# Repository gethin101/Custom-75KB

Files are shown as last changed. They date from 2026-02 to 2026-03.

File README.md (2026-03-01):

# Gethin-75 
A custom 75% mechanical keyboard with macro keys powered by a Raspberry pi pico and KMK firmware that I designed and built during Hackclub's Blueprint program - [project link](https://blueprint.hackclub.com/projects/12386)

I made this project to learn the fundamentals of how keyboards and macropads work, to improve my PCB design skills by learning how switch matrixes work and to get more familiar with modelling parts in CAD for 3D printing.

   

  <a href="#Keys">BOM</a> •
  <a href="#Images">Images</a> •
  <a href="#Firmware">Firmware</a> •
  <a href="#BOM">BOM</a> •
  <a href="#Full Wiring Table">Wiring</a> •
  <a href="#Keys">Keys</a> •
  <a href="#Stabilizers">Stabilizers</a> 

# Key Features
- **93 programmable macro keys**
- **Custom 2-layer PCB**
- **Powered by a Raspberry Pi Pico**
- **Custom KMK firmware**
- **Simple USB connectivity**
- **Inter-changable Cherry MX key switches**
- **3D printed case & plate**
- **Rubber feet pads for stability**
- **Easy assembly with no screws**

# Images
Here, you can see my KiCad schematic, PCB layout and 3D model of my PCB. On the right, you can see my keyboard bottom case I modelled in Fusion 360 as well as my custom plate and an assembly image.
<br>

<details>
<summary>Click to see schematic</summary>
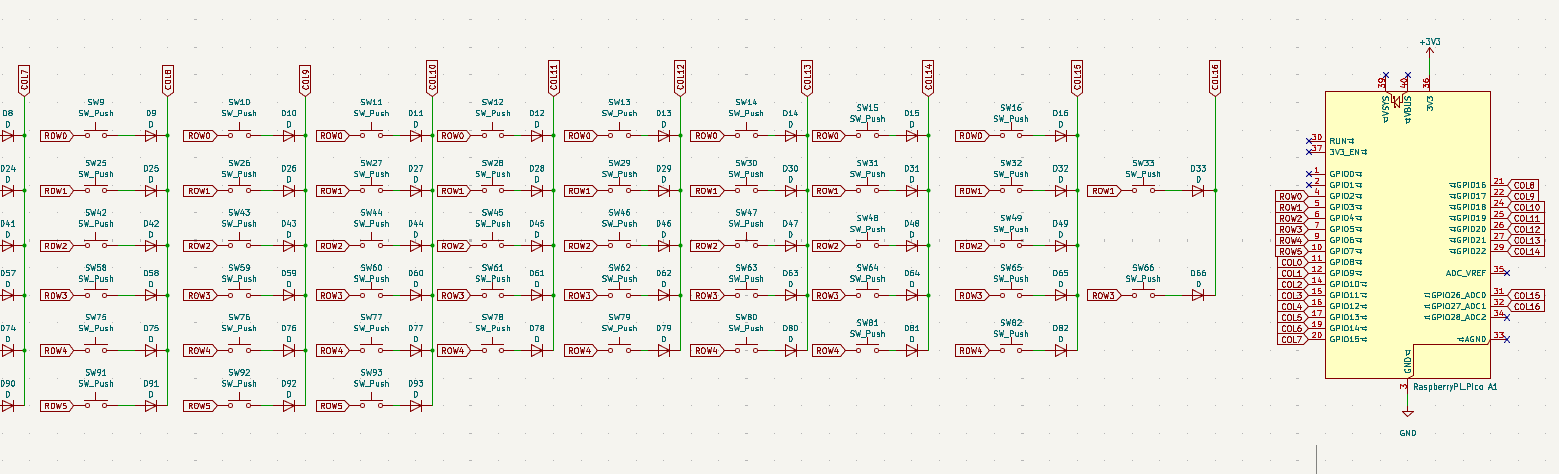
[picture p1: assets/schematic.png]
schematic

</details>

<details>
<summary>Click to see PCB</summary>
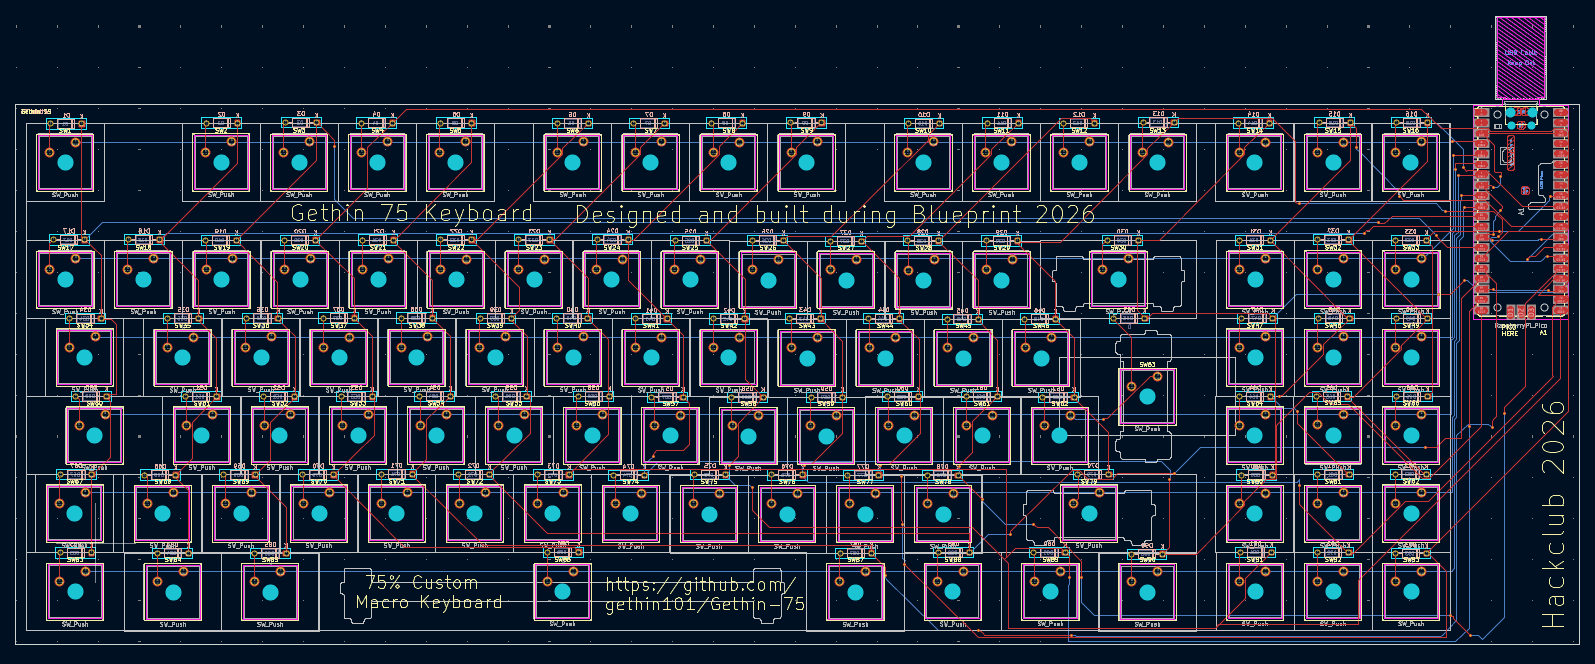
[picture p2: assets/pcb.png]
PCB

</details>

<details>
<summary>Click to see 3D PCB</summary>
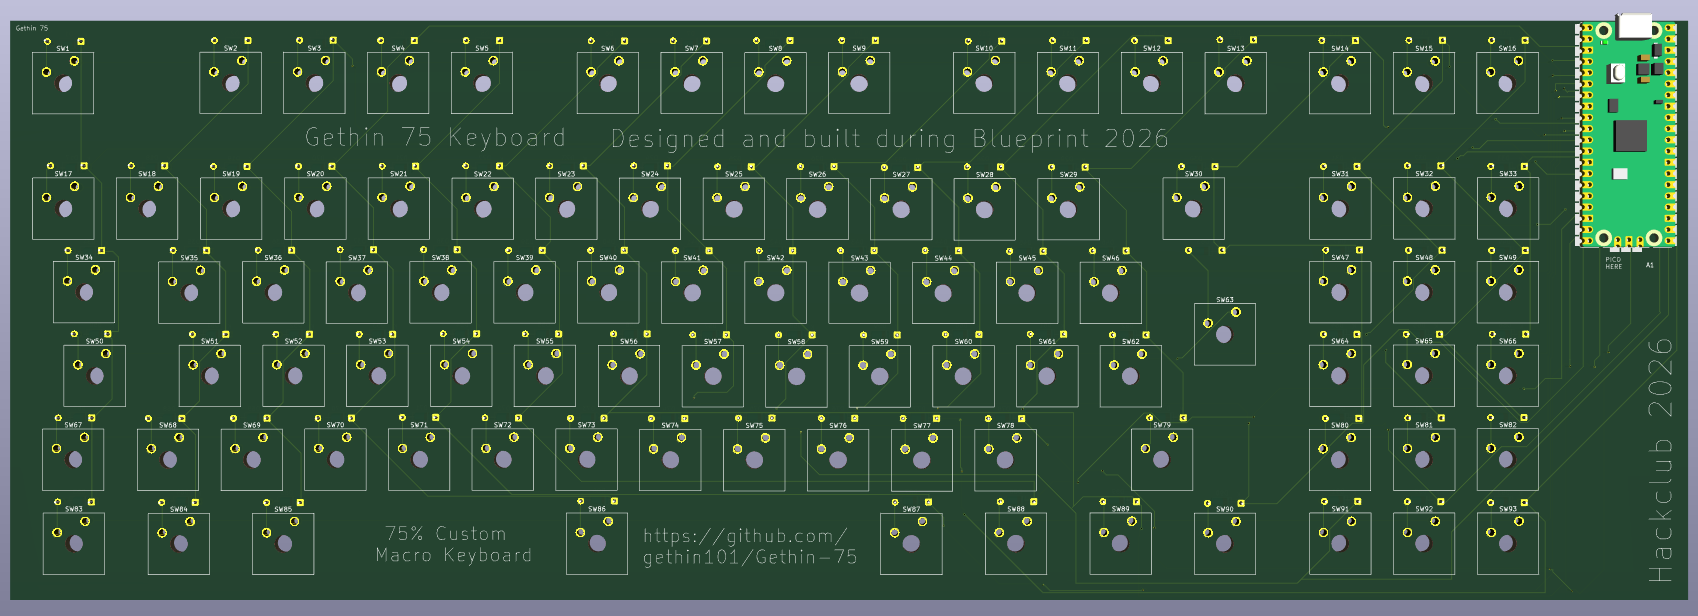
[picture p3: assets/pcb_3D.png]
3d pcb

</details>

**Click any of the images below or click above to see it in more detail**

| PCB | CAD |
|-----|-----|
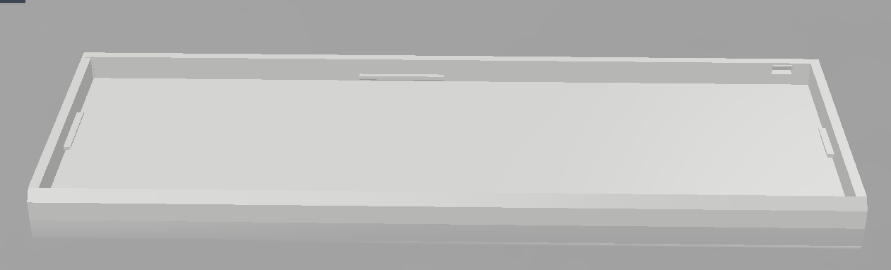
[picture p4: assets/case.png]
|  |  |
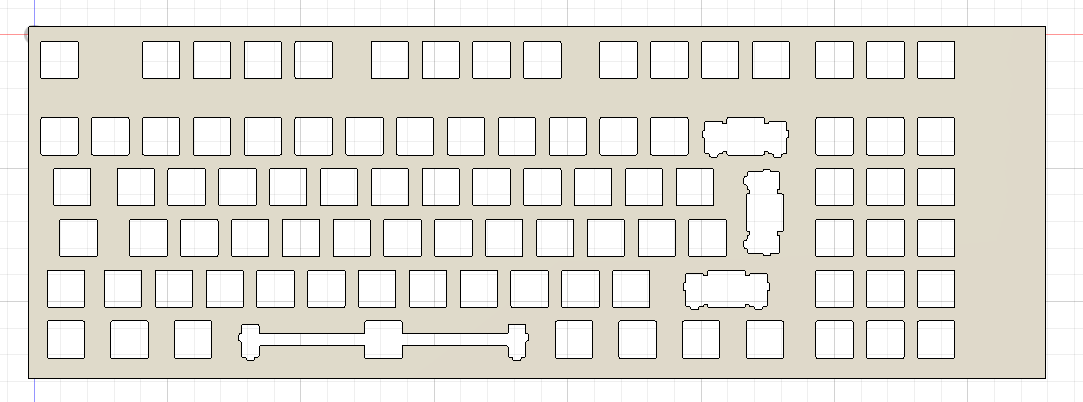
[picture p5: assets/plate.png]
|  |  |
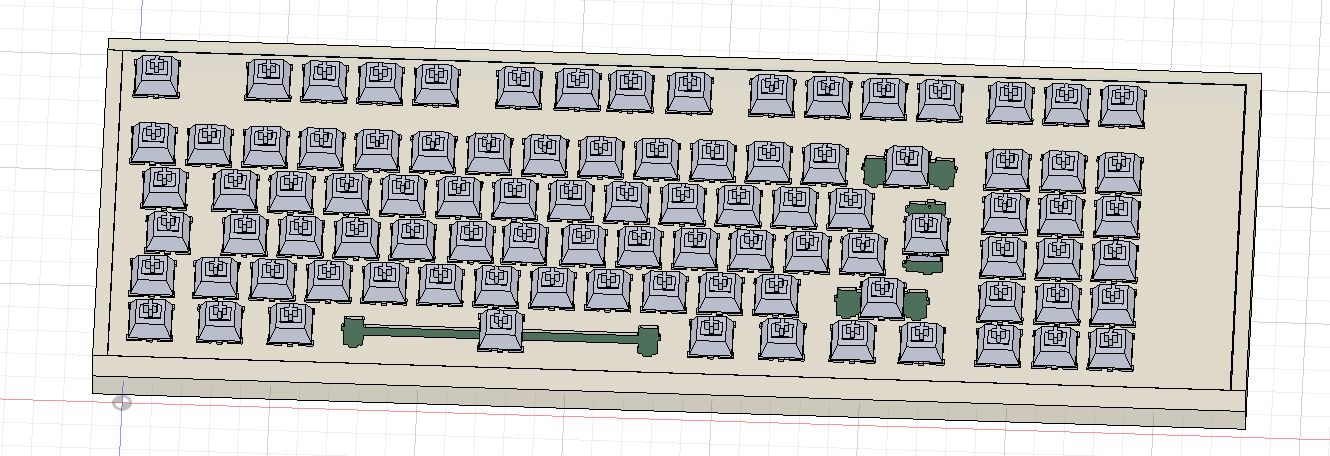
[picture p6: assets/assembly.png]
|  |  |

<details>
<summary>Click to see case model</summary>
case
</details>

<details>
<summary>Click to see plate model</summary>
plate
</details>

<details>
<summary>Click to see keyboard assembly</summary>
assembly
</details>

 

 # Full Wiring Table

<details>
<summary>Click to see full wiring table</summary>
<br>

| Net | GPIO | Notes |
|---|---|---|
| ROW0  | GP2  | Matrix  |
| ROW1  | GP3  | Matrix  |
| ROW2  | GP4  | Matrix  |
| ROW3  | GP5  | Matrix  |
| ROW4  | GP6  | Matrix  |
| ROW5  | GP7  | Matrix  |
| COL0  | GP8  | Matrix  |
| COL1  | GP9  | Matrix  |
| COL2  | GP10 | Matrix  |
| COL3  | GP11 | Matrix  |
| COL4  | GP12 | Matrix  |
| COL5  | GP13 | Matrix  |
| COL6  | GP14 | Matrix  |
| COL7  | GP15 | Matrix  |
| COL8  | GP16 | Matrix  |
| COL9  | GP17 | Matrix  |
| COL10 | GP18 | Matrix  |
| COL11 | GP19 | Matrix  |
| COL12 | GP20 | Matrix  |
| COL13 | GP21 | Matrix  |
| COL14 | GP22 | Matrix  |
| COL15 | GP26 | Matrix  |
| COL16 | GP27 | Matrix  |
| 3V3 | +3v3 | Pico |
| GND | GND  | Common  |

</details>

# Firmware
I have written my custom keyboard code in CircuitPython using KMK to control the keystrokes and I have made a macro handler at the start that means I can change the function of any of my keys whenever I want.

My macro keys at the moment:
- Previous song
- Play / Pause
- Next song
- Volume down
- Volume up
- Lock
- File Explorer
- Task Manager

**Setup:**
- Flash [CircuitPython](/Firmware/adafruit-circuitpython-raspberry_pi_pico2-en_GB-10.1.3.uf2) onto my pico
- Download KMK from [Github](/Firmware/kmk) and copy to root
- Download [code.py](/Firmware/code.py) onto the pico

# Keys
My keyboard is a 75% keyboard with a total of 93 keys - 85 normal and 8 custom macro keys.

Here is the link to my [keyboard layout](https://www.keyboard-layout-editor.com/#/gists/a3df558aee879b924d336356534e8c5d) <br>

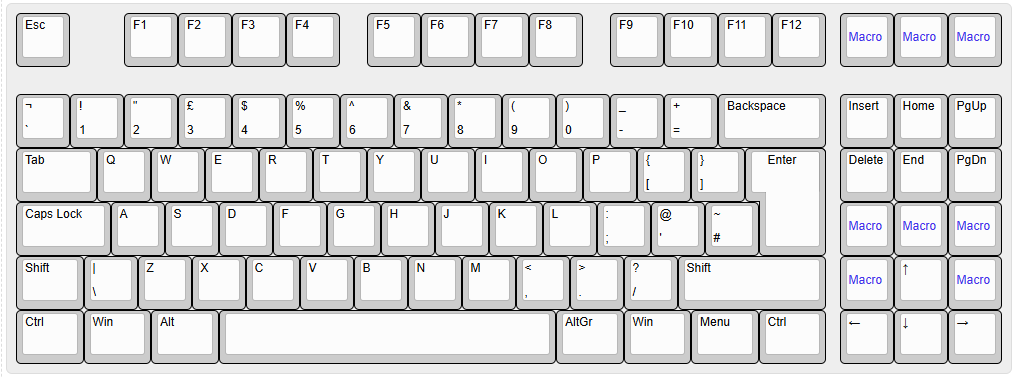
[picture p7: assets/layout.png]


---

# BOM
| Qty | Item | Notes | Cost (£) | USD ($) | Link |
|---|-----|---|---|---|---|
| 100 | MX-Style key switches | Black 100pcs | £15.28 | $20.60 | [AE](https://www.aliexpress.com/item/1005006091988869.html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)
| 126 | Cherry MX Key caps | Yunhu White | £2.04 | $2.75 | [AE](https://www.aliexpress.com/item/1005007321700850.html) |
| 1 | Raspberry Pi Pico | 2H | £5.40 | $7.28 | [PiHut](https://thepihut.com/products/raspberry-pi-pico-2?variant=54063366701441) |
| 5 | Plate-mount stabilizers | 4x 2u and 6.25u | £4.29 | $5.79 | [AE](https://www.aliexpress.com/item/1005001831944910.html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) |
| 100 | 1N4148 diodes | Through-hole | £0.76 | $1.02 | [AE](https://www.aliexpress.com/item/4001126137167.html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) |
| 50 | Rubber feet pads | 13x5.5mm | £0.76 | $1.02 | [AE](https://www.aliexpress.com/item/1005006832476105.html) |
| 5 | Custom PCB | (Quote estimate) | £ | $ | [JLCPCB]([https://www.aliexpress.com/item/1005006832476105.html](https://jlcpcb.com/)) |
| 1 | Micro USB -> USB cable | 0.5m | £0.76 | $1.01 | [AE](https://www.aliexpress.com/item/1005010780201113.html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) |
| 2 | 3D Print case and plate | #printing-legion | £ | $ | [Slack](https://hackclub.enterprise.slack.com/archives/C083P4FJM46) |
| **390** | **Total cost:** | **Not counting shipping** | **£29.29** | **$40.48** | [BOM](/Bom.md) |

# Stabilizers 

My spacebar, left shift, right shift, enter and backspace all need MX stabilizers as they are above 2u and these will be plate-mounted.

| Key | Size | Stabilizer |
|-----|---|---|
|Space| 6.25u| 6.25u plate-mount |
|R-Shift| 2.75u | 2u plate-mount |
|Enter | 2.25u | 2u plate-mount |
|Backspace | 2u | 2u plate-mount |

---

# Blueprint requirements

- [✅] A short description of what your project is  
- [✅] A couple of sentences on how to use your project  
- [✅] A couple of sentences on why you made the project  

- [✅ ] Screenshot of a full 3D model of your project  
- [✅ ] Screenshot of your PCB (if applicable)  
- [✅ ] Wiring diagram (if any wiring is not on a PCB)  
- [✅] Bill of Materials (BOM) in table format at the end of the README, with links  

- [✅] Fully original, customized design (not a direct copy of any guide)  
- [✅] Complete CAD assembly including all components (electronics included)  
- [✅] Firmware present (even if untested)  
- [ ] Design sanity‑checked with someone else  

- [ ] BOM in CSV format in the root directory, with links  
- [ ] PCB source files (.kicad_pro, .kicad_sch, gerbers.zip, etc.) if applicable  
- [ ] A .STEP file of the full 3D CAD model including electronics  
- [ ] Source CAD files (.f3d, .FCStd, etc., or OnShape public link in README)  
- [ ] All other project files included (firmware, libraries, references, etc.)  
- [ ] Repository organized into readable, logical folders  

> ⚠️ **Important:** Missing a complete .STEP file with all electronics and CAD will result in project rejection.

Designed and built by [@gethin101](https://github.com/gethin101)

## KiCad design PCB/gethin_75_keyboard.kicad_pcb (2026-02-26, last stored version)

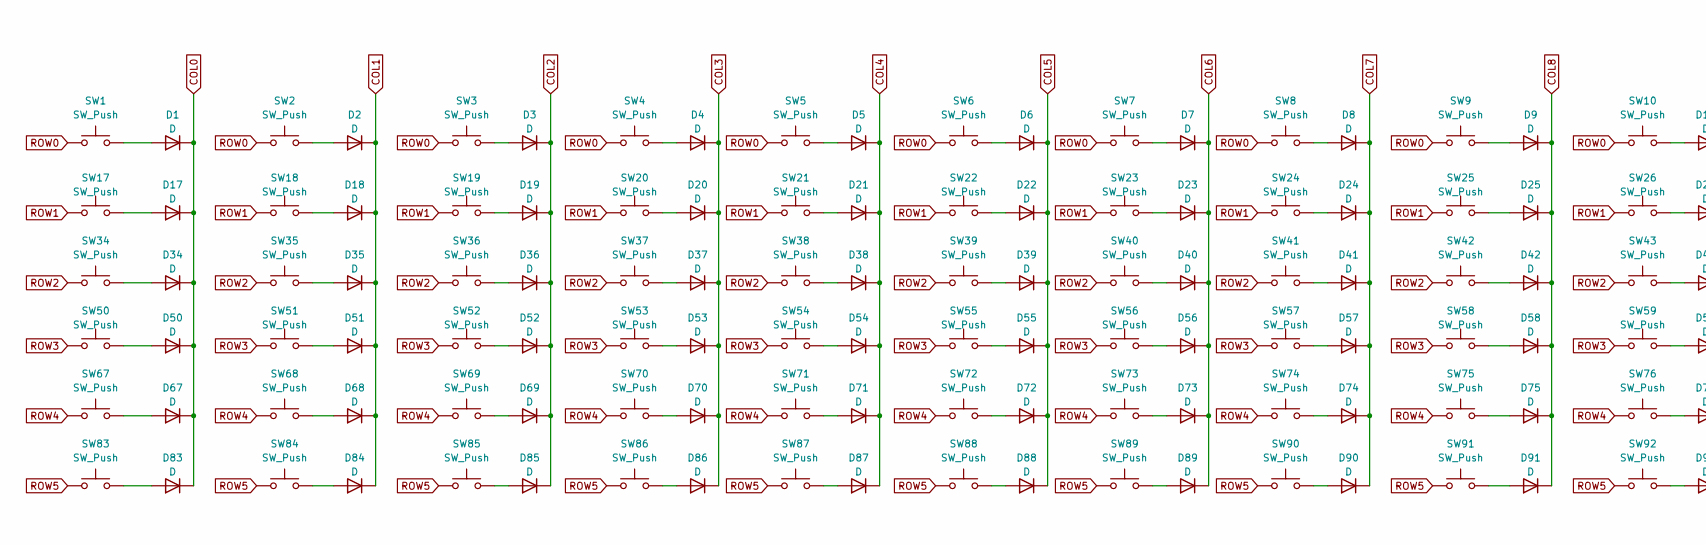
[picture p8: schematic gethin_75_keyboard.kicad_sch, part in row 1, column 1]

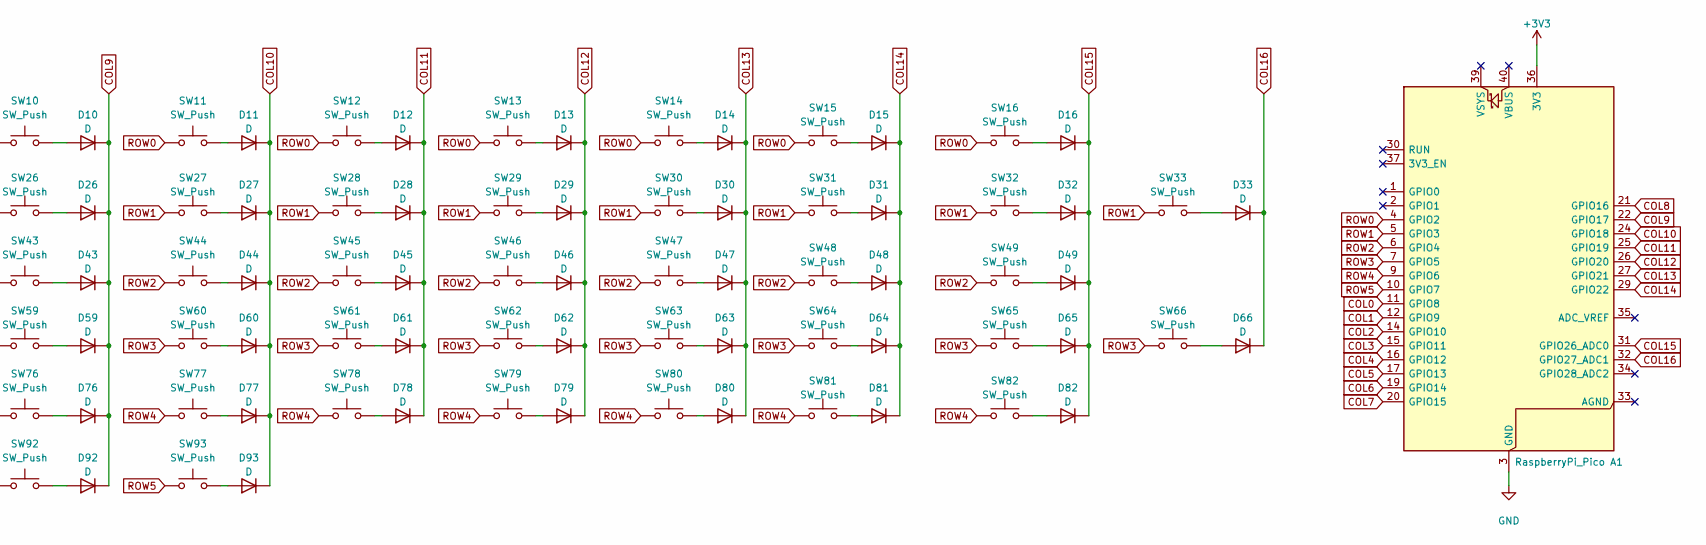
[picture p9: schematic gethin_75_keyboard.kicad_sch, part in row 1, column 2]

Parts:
A1: RaspberryPi_Pico; RaspberryPi_Pico_SMD_HandSolder
D1, D2, D3, D4, D5, D6, D7, D8, D9, D10, D11, D12, D13, D14, D15, D16, D17, D18, D19, D20, D21, D22, D23, D24, D25, D26, D27, D28, D29, D30, D31, D32, D33, D34, D35, D36, D37, D38, D39, D40, D41, D42, D43, D44, D45, D46, D47, D48, D49, D50, D51, D52, D53, D54, D55, D56, D57, D58, D59, D60, D61, D62, D63, D64, D65, D66, D67, D68, D69, D70, D71, D72, D73, D74, D75, D76, D77, D78, D79, D80, D81, D82, D83, D84, D85, D86, D87, D88, D89, D90, D91, D92, D93: D; D_DO-35_SOD27_P7.62mm_Horizontal
SW1, SW2, SW3, SW4, SW5, SW6, SW7, SW8, SW9, SW10, SW11, SW12, SW13, SW14, SW15, SW16, SW17, SW18, SW19, SW20, SW21, SW22, SW23, SW24, SW25, SW26, SW27, SW28, SW29, SW31, SW32, SW33, SW34, SW35, SW36, SW37, SW38, SW39, SW40, SW41, SW42, SW43, SW44, SW45, SW46, SW47, SW48, SW49, SW51, SW52, SW53, SW54, SW55, SW56, SW57, SW58, SW59, SW60, SW61, SW62, SW64, SW65, SW66, SW67, SW68, SW69, SW70, SW71, SW72, SW73, SW74, SW75, SW76, SW77, SW78, SW80, SW81, SW82, SW91, SW92, SW93: SW_Push; SW_Cherry_MX_1.00u_Plate
SW30: SW_Push; SW_Cherry_MX_2.00u_Plate
SW50: SW_Push; SW_Cherry_MX_1.75u_Plate
SW63: SW_Push; SW_Cherry_MX_2.25u_Plate
SW79: SW_Push; SW_Cherry_MX_2.75u_Plate
SW83, SW84, SW85, SW87, SW88, SW89, SW90: SW_Push; SW_Cherry_MX_1.25u_Plate
SW86: SW_Push; SW_Cherry_MX_6.25u_Plate

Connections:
+3V3: A1.36 (3V3)
COL0: A1.11 (GPIO8), D1.1 (K), D17.1 (K), D34.1 (K), D50.1 (K), D67.1 (K), D83.1 (K)
COL1: A1.12 (GPIO9), D2.1 (K), D18.1 (K), D35.1 (K), D51.1 (K), D68.1 (K), D84.1 (K)
COL2: A1.14 (GPIO10), D3.1 (K), D19.1 (K), D36.1 (K), D52.1 (K), D69.1 (K), D85.1 (K)
COL3: A1.15 (GPIO11), D4.1 (K), D20.1 (K), D37.1 (K), D53.1 (K), D70.1 (K), D86.1 (K)
COL4: A1.16 (GPIO12), D5.1 (K), D21.1 (K), D38.1 (K), D54.1 (K), D71.1 (K), D87.1 (K)
COL5: A1.17 (GPIO13), D6.1 (K), D22.1 (K), D39.1 (K), D55.1 (K), D72.1 (K), D88.1 (K)
COL6: A1.19 (GPIO14), D7.1 (K), D23.1 (K), D40.1 (K), D56.1 (K), D73.1 (K), D89.1 (K)
COL7: A1.20 (GPIO15), D8.1 (K), D24.1 (K), D41.1 (K), D57.1 (K), D74.1 (K), D90.1 (K)
COL8: A1.21 (GPIO16), D9.1 (K), D25.1 (K), D42.1 (K), D58.1 (K), D75.1 (K), D91.1 (K)
COL9: A1.22 (GPIO17), D10.1 (K), D26.1 (K), D43.1 (K), D59.1 (K), D76.1 (K), D92.1 (K)
COL10: A1.24 (GPIO18), D11.1 (K), D27.1 (K), D44.1 (K), D60.1 (K), D77.1 (K), D93.1 (K)
COL11: A1.25 (GPIO19), D12.1 (K), D28.1 (K), D45.1 (K), D61.1 (K), D78.1 (K)
COL12: A1.26 (GPIO20), D13.1 (K), D29.1 (K), D46.1 (K), D62.1 (K), D79.1 (K)
COL13: A1.27 (GPIO21), D14.1 (K), D30.1 (K), D47.1 (K), D63.1 (K), D80.1 (K)
COL14: A1.29 (GPIO22), D15.1 (K), D31.1 (K), D48.1 (K), D64.1 (K), D81.1 (K)
COL15: A1.31 (GPIO26_ADC0), D16.1 (K), D32.1 (K), D49.1 (K), D65.1 (K), D82.1 (K)
COL16: A1.32 (GPIO27_ADC1), D33.1 (K), D66.1 (K)
GND: A1.3 (GND), A1.8 (GND), A1.13 (GND), A1.18 (GND), A1.23 (GND), A1.28 (GND), A1.38 (GND)
unnamed: D1.2 (A), SW1.2
unnamed: D2.2 (A), SW2.2
unnamed: D3.2 (A), SW3.2
unnamed: D4.2 (A), SW4.2
unnamed: D5.2 (A), SW5.2
unnamed: D6.2 (A), SW6.2
unnamed: D7.2 (A), SW7.2
unnamed: D8.2 (A), SW8.2
unnamed: D9.2 (A), SW9.2
unnamed: D10.2 (A), SW10.2
unnamed: D11.2 (A), SW11.2
unnamed: D12.2 (A), SW12.2
unnamed: D13.2 (A), SW13.2
unnamed: D14.2 (A), SW14.2
unnamed: D15.2 (A), SW15.2
unnamed: D16.2 (A), SW16.2
unnamed: D17.2 (A), SW17.2
unnamed: D18.2 (A), SW18.2
unnamed: D19.2 (A), SW19.2
unnamed: D20.2 (A), SW20.2
unnamed: D21.2 (A), SW21.2
unnamed: D22.2 (A), SW22.2
unnamed: D23.2 (A), SW23.2
unnamed: D24.2 (A), SW24.2
unnamed: D25.2 (A), SW25.2
unnamed: D26.2 (A), SW26.2
unnamed: D27.2 (A), SW27.2
unnamed: D28.2 (A), SW28.2
unnamed: D29.2 (A), SW29.2
unnamed: D30.2 (A), SW30.2
unnamed: D31.2 (A), SW31.2
unnamed: D32.2 (A), SW32.2
unnamed: D33.2 (A), SW33.2
unnamed: D34.2 (A), SW34.2
unnamed: D35.2 (A), SW35.2
unnamed: D36.2 (A), SW36.2
unnamed: D37.2 (A), SW37.2
unnamed: D38.2 (A), SW38.2
unnamed: D39.2 (A), SW39.2
unnamed: D40.2 (A), SW40.2
unnamed: D41.2 (A), SW41.2
unnamed: D42.2 (A), SW42.2
unnamed: D43.2 (A), SW43.2
unnamed: D44.2 (A), SW44.2
unnamed: D45.2 (A), SW45.2
unnamed: D46.2 (A), SW46.2
unnamed: D47.2 (A), SW47.2
unnamed: D48.2 (A), SW48.2
unnamed: D49.2 (A), SW49.2
unnamed: D50.2 (A), SW50.2
unnamed: D51.2 (A), SW51.2
unnamed: D52.2 (A), SW52.2
unnamed: D53.2 (A), SW53.2
unnamed: D54.2 (A), SW54.2
unnamed: D55.2 (A), SW55.2
unnamed: D56.2 (A), SW56.2
unnamed: D57.2 (A), SW57.2
unnamed: D58.2 (A), SW58.2
unnamed: D59.2 (A), SW59.2
unnamed: D60.2 (A), SW60.2
unnamed: D61.2 (A), SW61.2
unnamed: D62.2 (A), SW62.2
unnamed: D63.2 (A), SW63.2
unnamed: D64.2 (A), SW64.2
unnamed: D65.2 (A), SW65.2
unnamed: D66.2 (A), SW66.2
unnamed: D67.2 (A), SW67.2
unnamed: D68.2 (A), SW68.2
unnamed: D69.2 (A), SW69.2
unnamed: D70.2 (A), SW70.2
unnamed: D71.2 (A), SW71.2
unnamed: D72.2 (A), SW72.2
unnamed: D73.2 (A), SW73.2
unnamed: D74.2 (A), SW74.2
unnamed: D75.2 (A), SW75.2
unnamed: D76.2 (A), SW76.2
unnamed: D77.2 (A), SW77.2
unnamed: D78.2 (A), SW78.2
unnamed: D79.2 (A), SW79.2
unnamed: D80.2 (A), SW80.2
unnamed: D81.2 (A), SW81.2
unnamed: D82.2 (A), SW82.2
unnamed: D83.2 (A), SW83.2
unnamed: D84.2 (A), SW84.2
unnamed: D85.2 (A), SW85.2
unnamed: D86.2 (A), SW86.2
unnamed: D87.2 (A), SW87.2
unnamed: D88.2 (A), SW88.2
unnamed: D89.2 (A), SW89.2
unnamed: D90.2 (A), SW90.2
unnamed: D91.2 (A), SW91.2
unnamed: D92.2 (A), SW92.2
unnamed: D93.2 (A), SW93.2
ROW0: A1.4 (GPIO2), SW1.1, SW2.1, SW3.1, SW4.1, SW5.1, SW6.1, SW7.1, SW8.1, SW9.1, SW10.1, SW11.1, SW12.1, SW13.1, SW14.1, SW15.1, SW16.1
ROW1: A1.5 (GPIO3), SW17.1, SW18.1, SW19.1, SW20.1, SW21.1, SW22.1, SW23.1, SW24.1, SW25.1, SW26.1, SW27.1, SW28.1, SW29.1, SW30.1, SW31.1, SW32.1, SW33.1
ROW2: A1.6 (GPIO4), SW34.1, SW35.1, SW36.1, SW37.1, SW38.1, SW39.1, SW40.1, SW41.1, SW42.1, SW43.1, SW44.1, SW45.1, SW46.1, SW47.1, SW48.1, SW49.1
ROW3: A1.7 (GPIO5), SW50.1, SW51.1, SW52.1, SW53.1, SW54.1, SW55.1, SW56.1, SW57.1, SW58.1, SW59.1, SW60.1, SW61.1, SW62.1, SW63.1, SW64.1, SW65.1, SW66.1
ROW4: A1.9 (GPIO6), SW67.1, SW68.1, SW69.1, SW70.1, SW71.1, SW72.1, SW73.1, SW74.1, SW75.1, SW76.1, SW77.1, SW78.1, SW79.1, SW80.1, SW81.1, SW82.1
ROW5: A1.10 (GPIO7), SW83.1, SW84.1, SW85.1, SW86.1, SW87.1, SW88.1, SW89.1, SW90.1, SW91.1, SW92.1, SW93.1

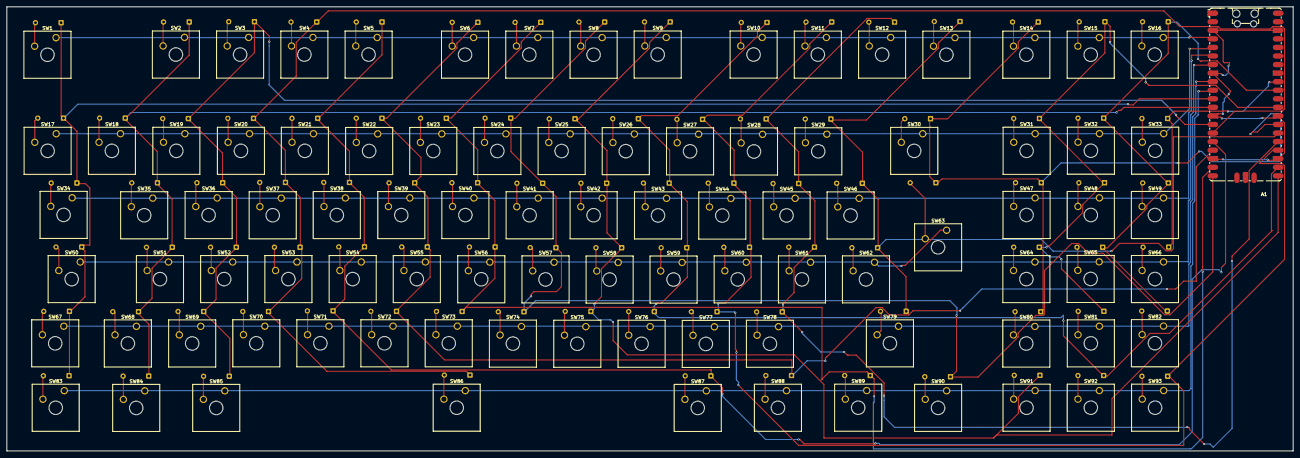
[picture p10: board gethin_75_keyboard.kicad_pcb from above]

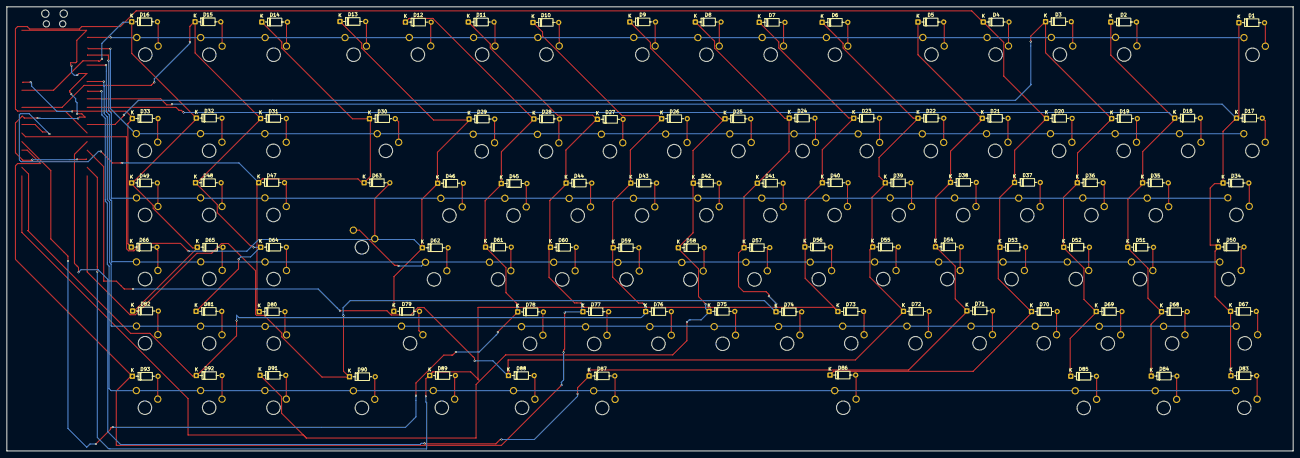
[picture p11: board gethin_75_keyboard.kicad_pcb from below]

Board: 2 copper layers, 381.7 x 131.8 mm, 187 parts (93 on the bottom side), 117 nets.

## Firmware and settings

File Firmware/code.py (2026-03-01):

#KMK - by gethin101
from kmk.bootcfg import bootcfg

bootcfg(
    usb_id={'manufacturer': "Gethin101", 'product': "Gethin-75"},
)


import board
from kmk.kmk_keyboard import KMKKeyboard
from kmk.scanners import DiodeOrientation
from kmk.keys import KC, make_key

MAC1 = make_key("MAC1")  # (back)
MAC2 = make_key("MAC2")  # (pause/play)
MAC3 = make_key("MAC3")  # (next)
MAC5 = make_key("MAC5")  # (vol down)
MAC6 = make_key("MAC6")  # (vol up)
MAC7 = make_key("MAC7")  # (lock)
MAC8 = make_key("MAC8")  # (file explorer)
MAC9 = make_key("MAC9")  # (task manager)


def handle_macro(keycode, keyboard):
    if keycode == MAC1:
        keyboard.tap_key(KC.MPRV)

    elif keycode == MAC2:
        keyboard.tap_key(KC.MPLY)

    elif keycode == MAC3:
        keyboard.tap_key(KC.MNXT)

    elif keycode == MAC5:
        keyboard.tap_key(KC.VOLD)

    elif keycode == MAC6:
        keyboard.tap_key(KC.VOLU)

    elif keycode == MAC7:
        keyboard.tap_key(KC.LGUI, KC.L)

    elif keycode == MAC8:
        keyboard.tap_key(KC.LGUI, KC.E)

    elif keycode == MAC9:
        keyboard.tap_key(KC.LCTRL, KC.LSHIFT, KC.ESC)


class Gethin75(KMKKeyboard):
    row_pins = (
        board.GP2,
        board.GP3,
        board.GP4,
        board.GP5,
        board.GP6,
        board.GP7,
    )

    col_pins = (
        board.GP8,
        board.GP9,
        board.GP10,
        board.GP11,
        board.GP12,
        board.GP13,
        board.GP14,
        board.GP15,
        board.GP16,
        board.GP17,
        board.GP18,
        board.GP19,
        board.GP20,
        board.GP21,
        board.GP22,
        board.GP26,
        board.GP27,
    )

    #switch if diodes wrong way
    diode_orientation = DiodeOrientation.COL2ROW


keyboard = Gethin75()



keyboard.keymap = [
    [
        KC.ESC, KC.F1, KC.F2, KC.F3, KC.F4,
        KC.F5, KC.F6, KC.F7, KC.F8,
        KC.F9, KC.F10, KC.F11, KC.F12,
        MAC1, MAC2, MAC3, KC.NO,
    ],

    [
        KC.GRAVE, KC.N1, KC.N2, KC.N3, KC.N4, KC.N5, KC.N6, KC.N7, KC.N8,
        KC.N9, KC.N0, KC.MINUS, KC.EQUAL, KC.BSPC, KC.INS, KC.HOME, KC.PGUP,
    ],

    [
        KC.TAB, KC.Q, KC.W, KC.E, KC.R, KC.T, KC.Y, KC.U, KC.I,
        KC.O, KC.P, KC.LBRC, KC.RBRC,
        KC.ENTER, KC.DEL, KC.END, KC.PGDN,
    ],

    [
        KC.CAPS, KC.A, KC.S, KC.D, KC.F, KC.G, KC.H, KC.J, KC.K,
        KC.L, KC.SCLN, KC.QUOT, KC.NUHS,
        MAC5, MAC6, MAC7, KC.NO,
    ],

    [
        KC.LSFT, KC.NUBS, KC.Z, KC.X, KC.C, KC.V, KC.B, KC.N, KC.M,
        KC.COMMA, KC.DOT, KC.SLSH, KC.RSFT,
        MAC8, KC.UP, MAC9, KC.NO,
    ],

    [
        KC.LCTL, KC.LGUI, KC.LALT, KC.SPC,
        KC.RALT, KC.RGUI, KC.APP, KC.RCTL,
        KC.LEFT, KC.DOWN, KC.RIGHT,
        KC.NO, KC.NO, KC.NO, KC.NO, KC.NO, KC.NO,
    ],
]


@keyboard.hook
def macro_hook(key, keyboard):
    handle_macro(key, keyboard)


if __name__ == '__main__':
    keyboard.go()

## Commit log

2026-02-23 Create CAD-models
2026-03-01 Rename Screenshot 2026-03-01 133340.png to schematic.png
2026-03-01 Rename Screenshot 2026-03-01 133430.png to pcb.png
2026-03-01 Rename Screenshot 2026-03-01 133520.png to pcb_3D.png
2026-03-01 Rename Screenshot 2026-03-01 133650.png to case.png
2026-03-01 Rename Screenshot 2026-03-01 133741.png to plate.png
2026-03-01 Rename Screenshot 2026-03-01 133848.png to assembly.png
